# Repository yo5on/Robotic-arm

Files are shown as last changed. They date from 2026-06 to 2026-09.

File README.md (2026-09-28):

<div align="center">

projects

<samp><b>ESP32 ROBOTIC ARM</b></samp>

<samp>robotics · esp32 · c/c++ · embedded systems</samp>

</div>

---

<div align="center"><samp>An ESP32-based 4-DOF robotic arm controlled wirelessly using an RC transmitter and receiver. The project demonstrates embedded control, servo motor manipulation, wireless communication, and coordinated robotic movement for pick-and-place applications.</samp></div>

---

<div align="center">
<samp><b>Project Overview</b></samp>
</div>

<samp>This project implements a four-degree-of-freedom robotic arm using an ESP32 microcontroller and a FlySky RC transmitter and receiver.</samp>

<samp>The system converts wireless control inputs into servo motor movements, allowing independent control of the arm's base, shoulder, elbow, and gripper.</samp>

<samp>The project provides practical experience with:</samp>

- <samp>Embedded systems</samp>
- <samp>Wireless control</samp>
- <samp>Servo motor control</samp>
- <samp>Microcontroller programming</samp>
- <samp>Robotic motion</samp>
- <samp>Hardware interfacing</samp>
- <samp>Pick-and-place automation</samp>

---

<div align="center">
<samp><b>Project Images</b></samp>
</div>

<table align="center">
<tr><th><samp>Robotic Arm</samp></th><th><samp>Wiring Diagram</samp></th></tr>
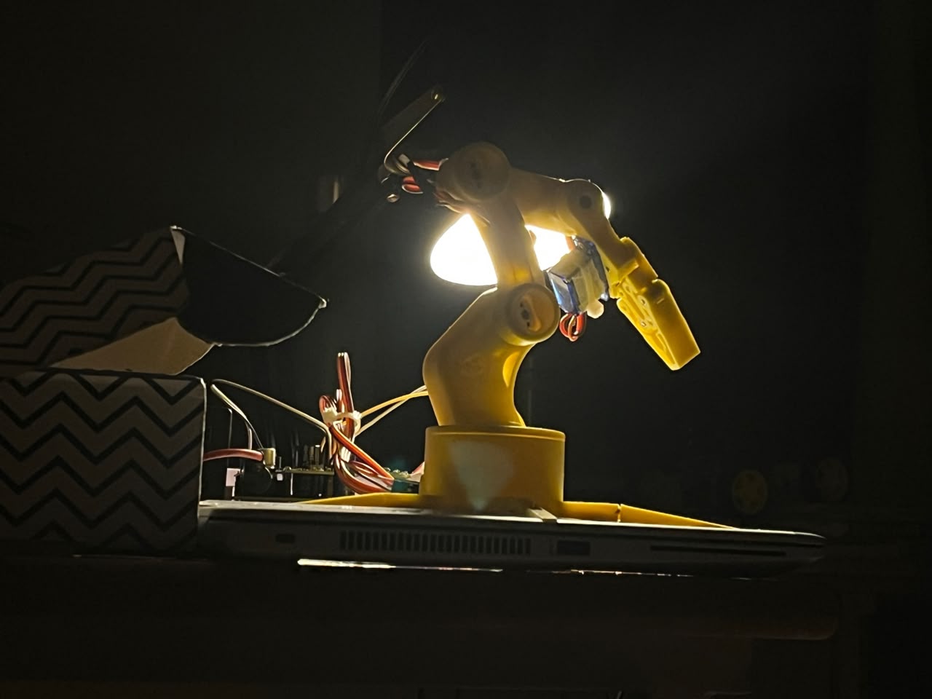
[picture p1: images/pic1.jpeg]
Robotic Arm
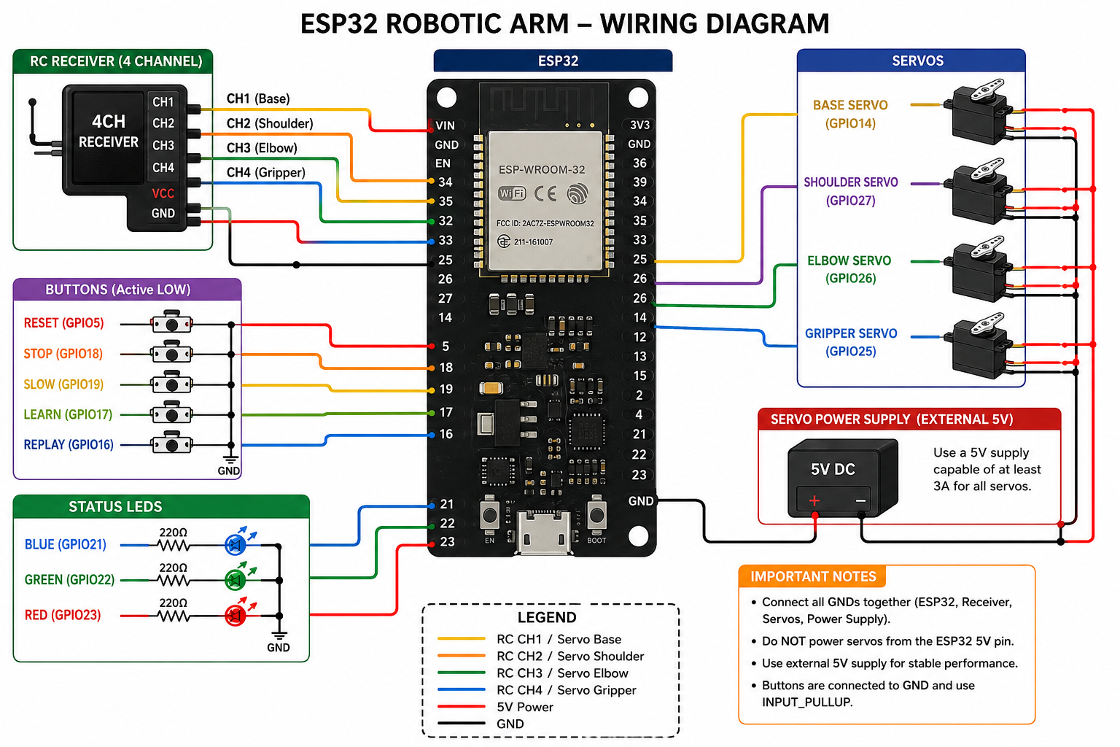
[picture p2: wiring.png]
Wiring Diagram
<tr><td></td><td></td></tr>
</table>

---

<div align="center">
<samp><b>Features</b></samp>
</div>

- <samp>Wireless RC control</samp>
- <samp>Four degrees of freedom</samp>
- <samp>Independent servo motor control</samp>
- <samp>Responsive robotic arm movement</samp>
- <samp>LED-based system status indication</samp>
- <samp>Push-button controls</samp>
- <samp>Pick-and-place functionality</samp>
- <samp>Modular hardware and software design</samp>
- <samp>Expandable architecture for future development</samp>

---

<div align="center">
<samp><b>Hardware Components</b></samp>
</div>

<table align="center">
<tr><th><samp>Component</samp></th><th><samp>Quantity</samp></th></tr>
<tr><td><samp>ESP32 Development Board</samp></td><td><samp>1</samp></td></tr>
<tr><td><samp>Servo Motors</samp></td><td><samp>4</samp></td></tr>
<tr><td><samp>FlySky Receiver</samp></td><td><samp>1</samp></td></tr>
<tr><td><samp>Push Buttons</samp></td><td><samp>5</samp></td></tr>
<tr><td><samp>LEDs</samp></td><td><samp>3</samp></td></tr>
<tr><td><samp>Robotic Arm Chassis</samp></td><td><samp>1</samp></td></tr>
<tr><td><samp>5V Power Supply</samp></td><td><samp>1</samp></td></tr>
<tr><td><samp>Connecting Wires</samp></td><td><samp>As required</samp></td></tr>
<tr><td><samp>Breadboard / PCB</samp></td><td><samp>Optional</samp></td></tr>
</table>

---

<div align="center">
<samp><b>Wiring</b></samp>
</div>

<samp>The complete wiring configuration is provided below.</samp>

<div align="center">Wiring Diagram</div>

---

<div align="center">
<samp><b>Repository Structure</b></samp>
</div>

```text
Robotic-arm/
│
├── 3dparts/
│   └── *.stl
├── images/
│   ├── pic1.jpeg
│   ├── pic2.jpeg
│   └── pic3.jpeg
├── README.md
├── code.ino
└── wiring.png
```

---

<div align="center">
<samp><b>Getting Started</b></samp>
</div>

<samp><b>Prerequisites</b></samp>

<samp>Before setting up the project, ensure that the following are available:</samp>

- <samp>Arduino IDE</samp>
- <samp>ESP32 board support package</samp>
- <samp>ESP32Servo library</samp>
- <samp>ESP32 development board</samp>
- <samp>FlySky transmitter and receiver</samp>
- <samp>Required servo motors</samp>
- <samp>Suitable 5V power supply</samp>

<samp><b>Clone the Repository</b></samp>

```bash
git clone https://github.com/yo5on/Robotic-arm.git
cd Robotic-arm
```

<samp><b>Open the Project</b></samp>

<samp>Open <code>code.ino</code> in the Arduino IDE.</samp>

<samp><b>Install Required Libraries</b></samp>

<samp>Install the following components through the Arduino IDE:</samp>

- <samp>ESP32 Board Package</samp>
- <samp>ESP32Servo Library</samp>

<samp><b>Configure the ESP32</b></samp>

<samp>1. Connect the ESP32 to the computer.</samp>

<samp>2. Select the appropriate ESP32 board from the Arduino IDE board menu.</samp>

<samp>3. Select the correct COM port.</samp>

<samp>4. Verify the wiring connections.</samp>

<samp>5. Open <code>code.ino</code>.</samp>

<samp><b>Upload the Code</b></samp>

<samp>Click <strong>Upload</strong> in the Arduino IDE and wait for the upload process to complete.</samp>

<samp>Once the code has been uploaded, power the robotic arm and transmitter/receiver system.</samp>

---

<div align="center">
<samp><b>Controls</b></samp>
</div>

<samp>The robotic arm is controlled through four RC channels:</samp>

<table align="center">
<tr><th><samp>Channel</samp></th><th><samp>Function</samp></th></tr>
<tr><td><samp>CH1</samp></td><td><samp>Base Rotation</samp></td></tr>
<tr><td><samp>CH2</samp></td><td><samp>Shoulder Movement</samp></td></tr>
<tr><td><samp>CH3</samp></td><td><samp>Elbow Movement</samp></td></tr>
<tr><td><samp>CH4</samp></td><td><samp>Gripper Control</samp></td></tr>
</table>

<samp>Servo limits and control ranges can be adjusted in the Arduino source code according to the mechanical configuration of the arm.</samp>

---

<div align="center">
<samp><b>System Architecture</b></samp>
</div>

```text
RC Transmitter
      |
      v
FlySky Receiver
      |
      v
     ESP32
      |
      +---- Base Servo
      |
      +---- Shoulder Servo
      |
      +---- Elbow Servo
      |
      +---- Gripper Servo
```

---

<div align="center">
<samp><b>Working Principle</b></samp>
</div>

<samp>1. The RC transmitter generates control signals based on user input.</samp>

<samp>2. The FlySky receiver receives the wireless signals.</samp>

<samp>3. The ESP32 reads the corresponding receiver channels.</samp>

<samp>4. The input values are mapped to appropriate servo positions.</samp>

<samp>5. The four servo motors move the robotic arm according to the received commands.</samp>

<samp>6. LEDs provide system status information.</samp>

<samp>7. Push buttons provide additional functionality such as mode selection, reset, or calibration.</samp>

---

<div align="center">
<samp><b>Applications</b></samp>
</div>

- <samp>Pick-and-place systems</samp>
- <samp>Embedded robotics</samp>
- <samp>Wireless robotic control</samp>
- <samp>Servo motor coordination</samp>
- <samp>Robotic manipulation</samp>
- <samp>Industrial automation concepts</samp>
- <samp>Autonomous robotic systems</samp>

---

<div align="center">
<samp><b>Future Improvements</b></samp>
</div>

- <samp>Inverse kinematics</samp>
- <samp>Preset position memory</samp>
- <samp>Mobile application control</samp>
- <samp>Wi-Fi and Bluetooth control</samp>
- <samp>Camera integration</samp>
- <samp>AI-based object detection</samp>
- <samp>Autonomous pick-and-place operations</samp>
- <samp>Motion planning and trajectory optimization</samp>
- <samp>Object tracking and classification</samp>

---

<div align="center">
<samp><b>Technologies</b></samp>
</div>

<table align="center">
<tr><th><samp>Category</samp></th><th><samp>Technology</samp></th></tr>
<tr><td><samp>Microcontroller</samp></td><td><samp>ESP32</samp></td></tr>
<tr><td><samp>Programming</samp></td><td><samp>C/C++</samp></td></tr>
<tr><td><samp>Development Environment</samp></td><td><samp>Arduino IDE</samp></td></tr>
<tr><td><samp>Wireless Control</samp></td><td><samp>FlySky RC Transmitter/Receiver</samp></td></tr>
<tr><td><samp>Actuators</samp></td><td><samp>Servo Motors</samp></td></tr>
<tr><td><samp>Communication</samp></td><td><samp>RC Receiver Channels</samp></td></tr>
</table>

---

<div align="center">
<samp><b>Author</b></samp>
</div>

<div align="center">
<samp><strong>Yoson</strong></samp>

<samp>Computer Science student interested in AI/ML, robotics, embedded systems, and automation.</samp>

<samp>GitHub: https://github.com/yo5on</samp>
</div>

---

<div align="center">
<samp><b>License</b></samp>
</div>

<samp>This project is intended for educational and personal use. You are free to explore, modify, and extend the project for your own robotics and embedded systems experiments.</samp>

<div align="center">
<samp>If you find this project useful, consider giving the repository a star.</samp>
</div>

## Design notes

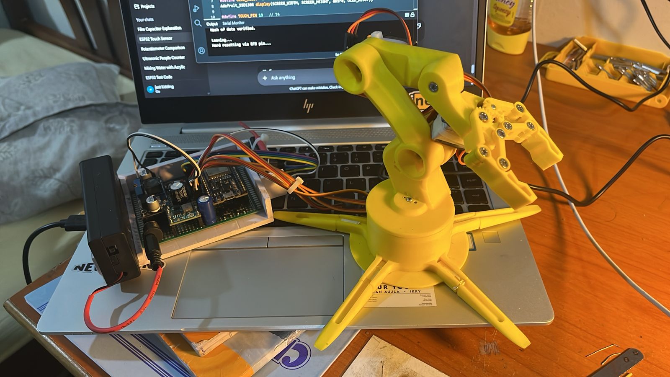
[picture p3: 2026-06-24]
images/pic2.jpeg

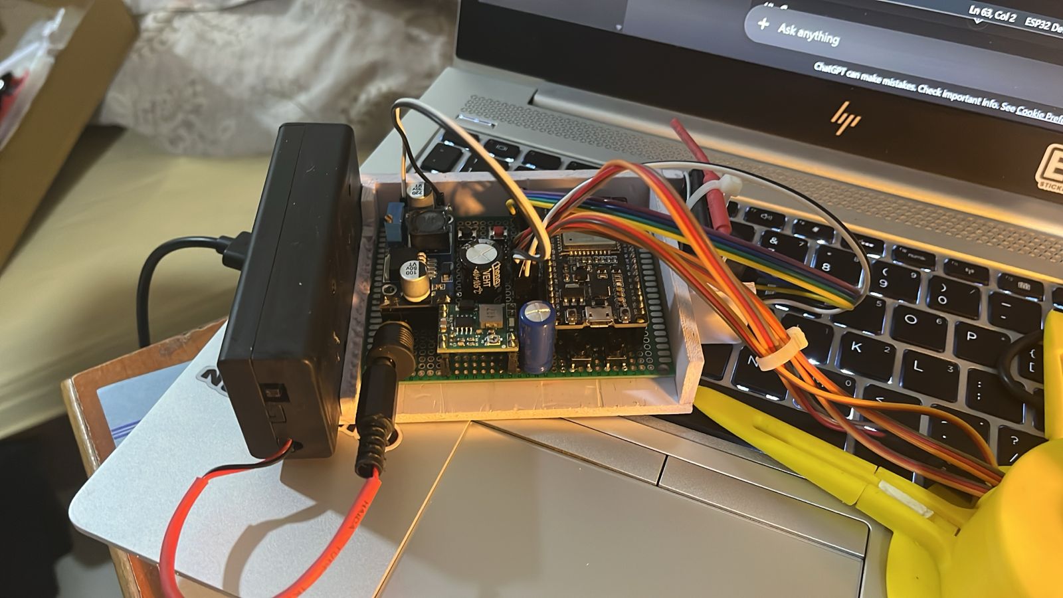
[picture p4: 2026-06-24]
images/pic3.jpeg

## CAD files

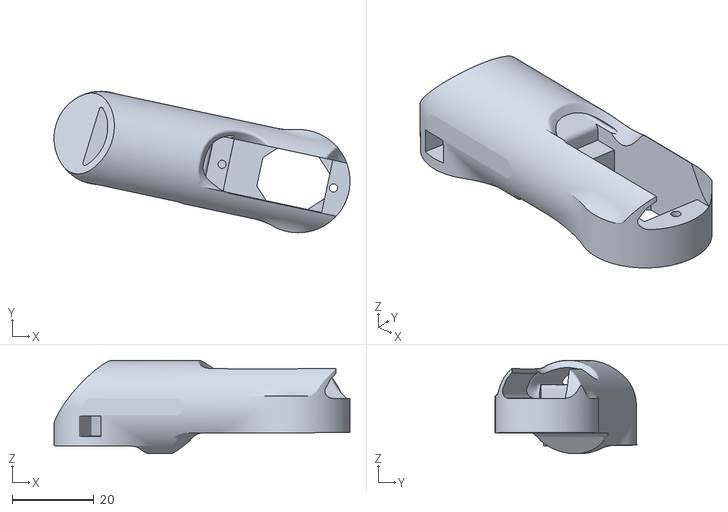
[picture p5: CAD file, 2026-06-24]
3dparts/arm.stl
72.2 x 34.5 x 22.8

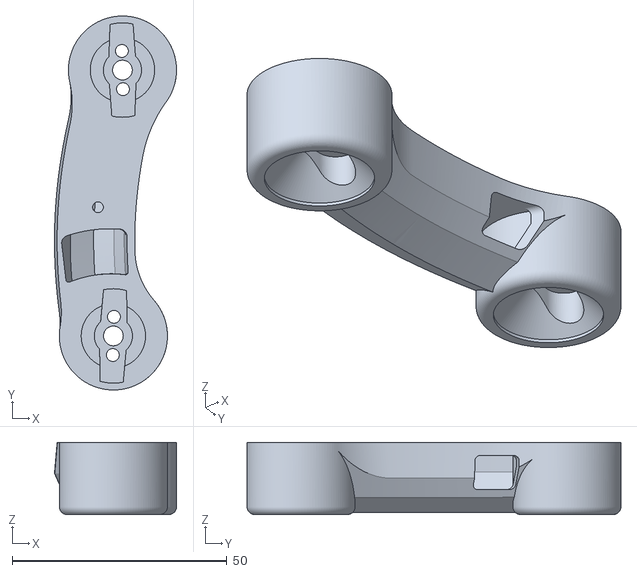
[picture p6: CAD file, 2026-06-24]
3dparts/forearm.stl
28.5 x 87.2 x 16.8

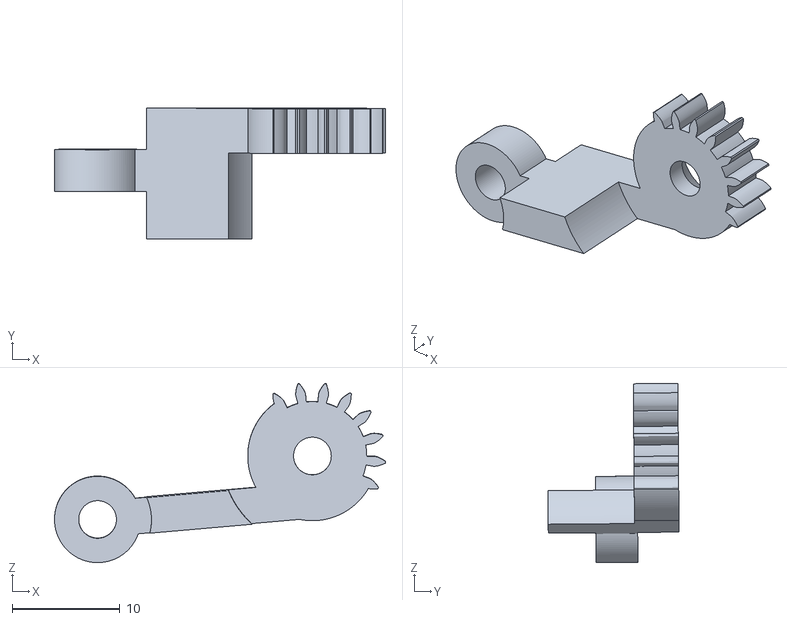
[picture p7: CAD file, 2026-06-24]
3dparts/gear2.stl
30.7 x 12.2 x 16.6

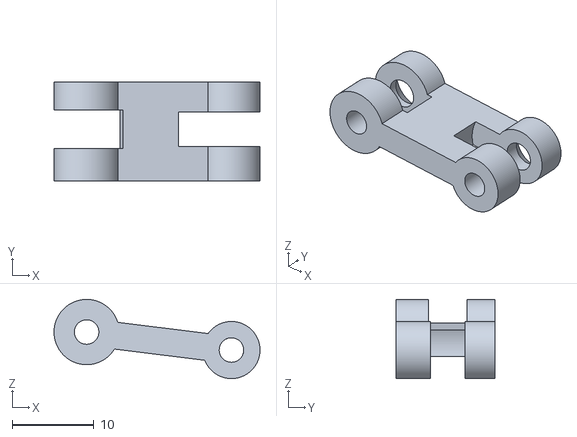
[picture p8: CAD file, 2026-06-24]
3dparts/bar1.stl
25.3 x 12.1 x 9.70

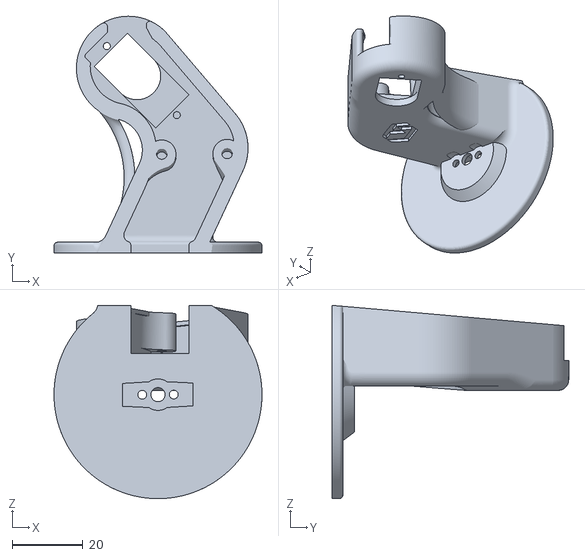
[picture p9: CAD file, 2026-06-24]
3dparts/centralshaft.stl
58.8 x 66.9 x 54.6

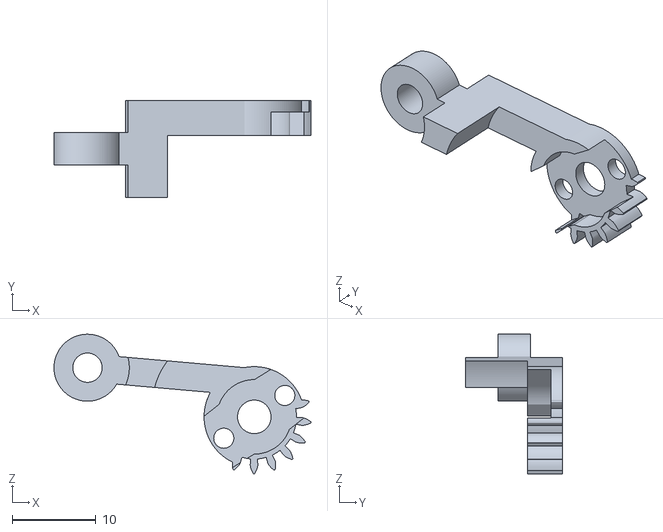
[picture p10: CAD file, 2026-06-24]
3dparts/gear1.stl
30.7 x 11.5 x 16.7

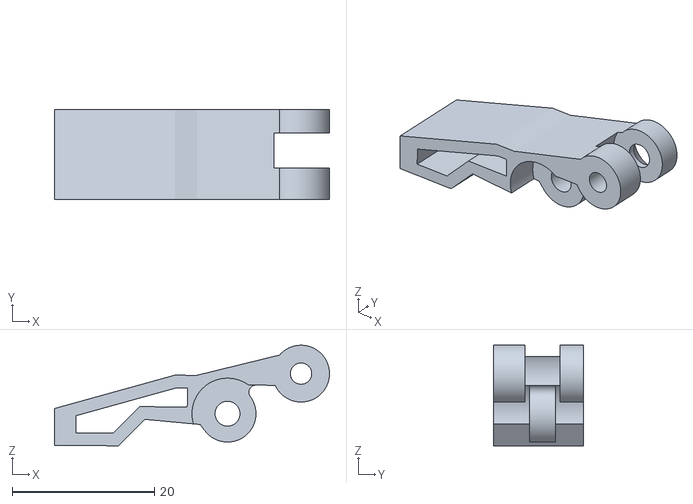
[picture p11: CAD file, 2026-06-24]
3dparts/claw1.stl
38.7 x 12.6 x 14.2

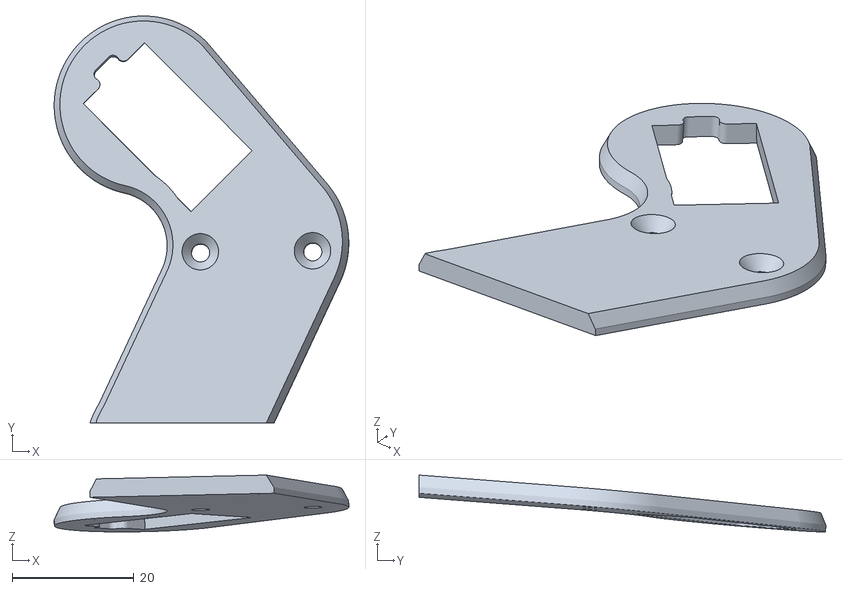
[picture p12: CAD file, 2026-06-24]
3dparts/shaftcover.stl
48.5 x 67.0 x 9.36

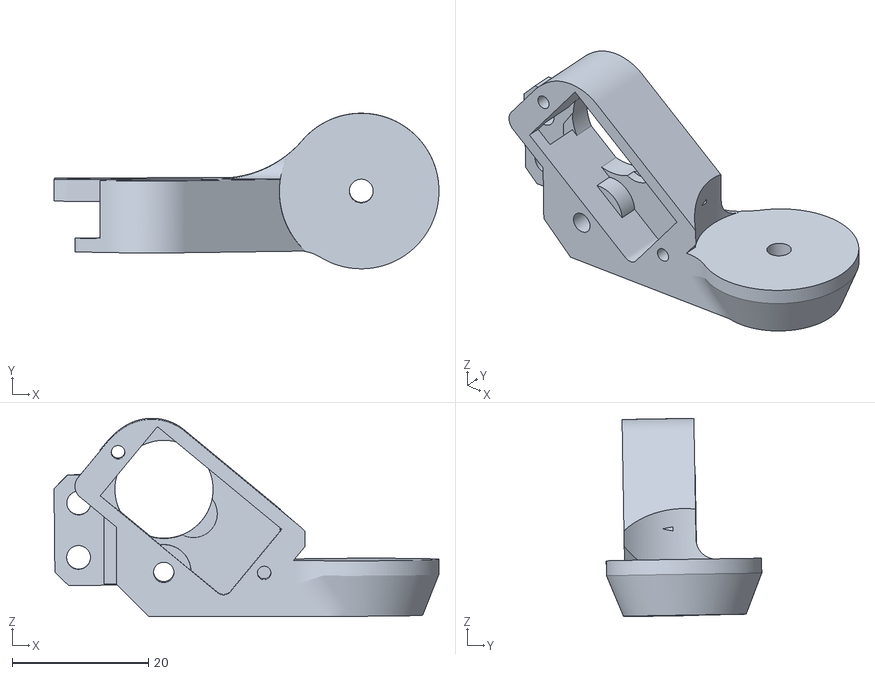
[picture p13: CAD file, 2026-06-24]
3dparts/clawbase.stl
56.5 x 22.8 x 29.1

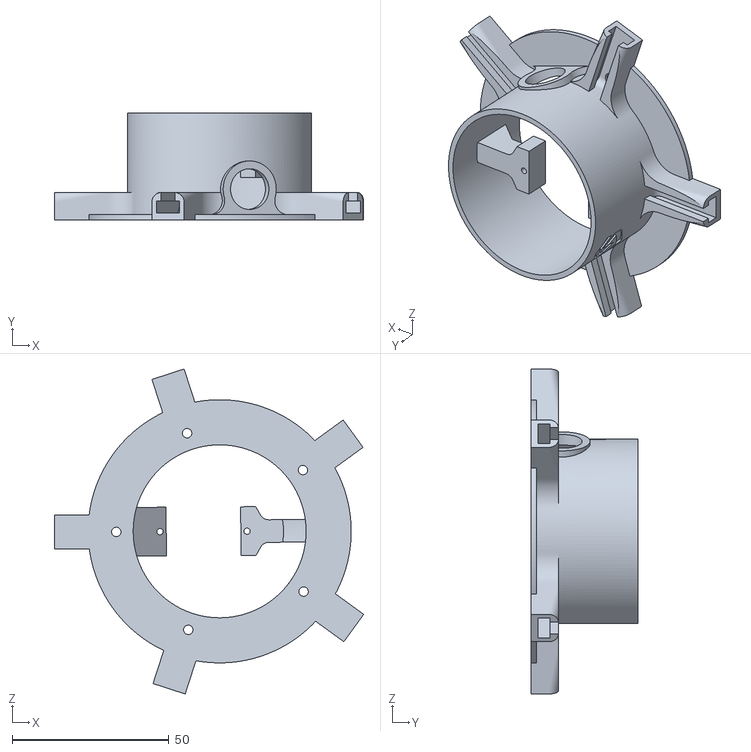
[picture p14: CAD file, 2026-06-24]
3dparts/base.stl
98.8 x 34.1 x 103.8

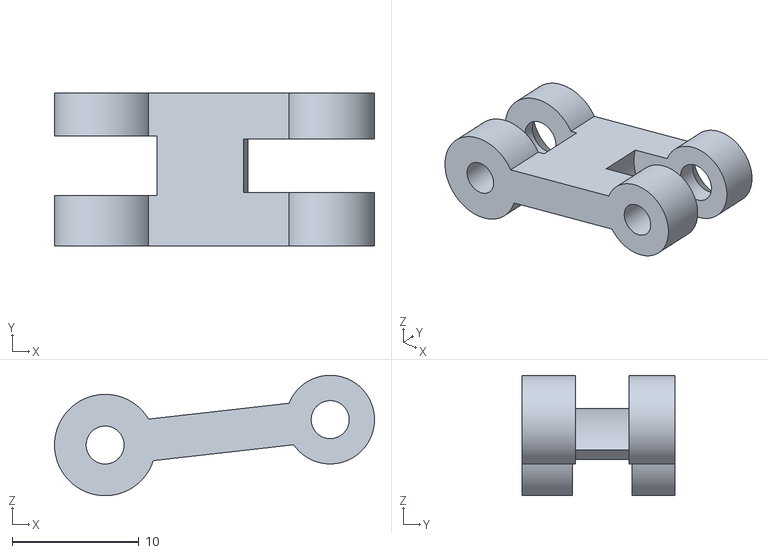
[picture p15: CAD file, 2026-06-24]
3dparts/bar2.stl
25.3 x 12.1 x 9.50

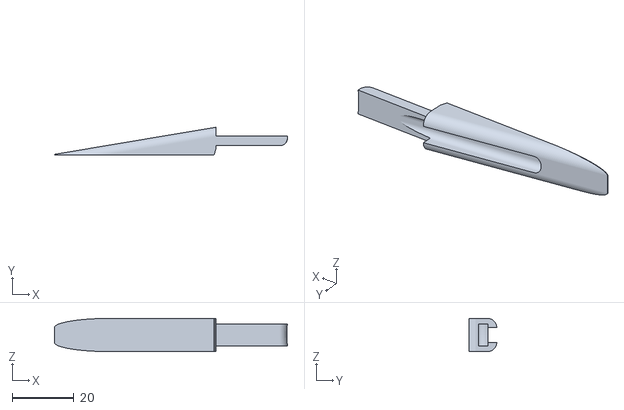
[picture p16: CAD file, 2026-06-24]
3dparts/leg.stl
75.7 x 8.96 x 10.8

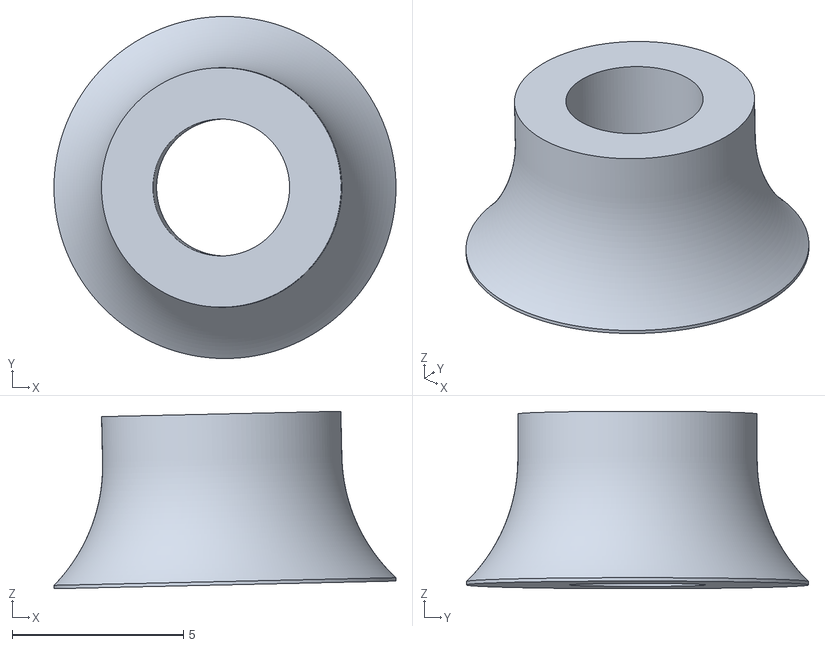
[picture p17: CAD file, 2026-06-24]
3dparts/smalltube.stl
10.00 x 10.00 x 5.19

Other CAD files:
3dparts/claw2.stl

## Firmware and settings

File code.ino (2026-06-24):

#include <Arduino.h>
#include <ESP32Servo.h>

// ===== Servos =====
Servo baseServo, shoulderServo, elbowServo, gripperServo;

// ===== Receiver pins =====
const int ch1Pin = 34;
const int ch2Pin = 35;
const int ch3Pin = 32;
const int ch4Pin = 33;

// ===== Servo pins =====
const int basePin = 14;
const int shoulderPin = 27;
const int elbowPin = 26;
const int gripperPin = 25;

// ===== Button pins =====
#define BTN_RESET   5
#define BTN_STOP    18
#define BTN_SLOW    19
#define BTN_LEARN   17
#define BTN_REPLAY  16

// ===== LED pins =====
#define LED_BLUE   21
#define LED_GREEN  22
#define LED_RED    23

// ===== Timing =====
const unsigned long SHORT_PRESS = 800;
const unsigned long DOUBLE_CLICK_GAP = 400;

// ===== Speed =====
bool slowMode = false;
unsigned long moveDelay = 2;
const unsigned long SLOW_DELAY = 25;

// ===== Button struct =====
struct Button {
  int pin;
  bool pressed;
  unsigned long t;
};

Button btnReset  = {BTN_RESET, false, 0};
Button btnStop   = {BTN_STOP, false, 0};
Button btnSlow   = {BTN_SLOW, false, 0};
Button btnLearn  = {BTN_LEARN, false, 0};
Button btnReplay = {BTN_REPLAY, false, 0};

// ===== States =====
bool stopMode = false;
bool learnMode = false;
bool replayOnce = false;
bool replayLoop = false;

// ===== Replay double click =====
bool replayPending = false;
unsigned long replayClickTime = 0;

// ===== Memory =====
#define MAX_STEPS 200
int baseMem[MAX_STEPS], shoulderMem[MAX_STEPS], elbowMem[MAX_STEPS], gripperMem[MAX_STEPS];
int stepCount = 0;

// ===== Reset confirmation =====
bool resetConfirm = false;
unsigned long resetTimer = 0;
int resetStep = 0;
bool resetState = false;

// ===== Blink timers =====
unsigned long redTimer = 0, blueTimer = 0;
int redStep = 0, blueStep = 0;
bool redState = false, blueState = false;

// ===== Button handler =====
void handleButton(Button &b, void (*action)()) {
  if (digitalRead(b.pin) == LOW && !b.pressed) {
    b.pressed = true;
    b.t = millis();
  }
  if (digitalRead(b.pin) == HIGH && b.pressed) {
    b.pressed = false;
    if (millis() - b.t < SHORT_PRESS) action();
  }
}

// ===== Button actions =====
void resetShort() {
  stopMode = false;
  baseServo.write(90);
  shoulderServo.write(90);
  elbowServo.write(90);
  gripperServo.write(45);

  resetConfirm = true;
  resetStep = 0;
  resetTimer = millis();
}

void stopShort() { stopMode = !stopMode; }

void slowShort() {
  slowMode = !slowMode;
  moveDelay = slowMode ? SLOW_DELAY : 2;
}

void learnShort() {
  learnMode = !learnMode;
  if (learnMode) stepCount = 0;
}

void replayShort() {
  unsigned long now = millis();
  if (replayPending && (now - replayClickTime <= DOUBLE_CLICK_GAP)) {
    replayLoop = !replayLoop;
    replayOnce = false;
    replayPending = false;
  } else {
    replayPending = true;
    replayClickTime = now;
  }
}

// ===== Blink helpers =====
bool doubleBlink(unsigned long &t, int &s, bool &st) {
  const unsigned long p[4] = {120,120,120,600};
  if (millis() - t >= p[s]) {
    t = millis();
    s = (s + 1) % 4;
    st = (s == 0 || s == 2);
  }
  return st;
}

bool resetBlink() {
  const unsigned long p[4] = {120,120,120,600};
  if (millis() - resetTimer >= p[resetStep]) {
    resetTimer = millis();
    resetStep++;
    resetState = (resetStep == 1 || resetStep == 3);
    if (resetStep >= 4) {
      resetConfirm = false;
      resetState = false;
    }
  }
  return resetState;
}

void setup() {
  pinMode(ch1Pin, INPUT);
  pinMode(ch2Pin, INPUT);
  pinMode(ch3Pin, INPUT);
  pinMode(ch4Pin, INPUT);

  pinMode(BTN_RESET, INPUT_PULLUP);
  pinMode(BTN_STOP, INPUT_PULLUP);
  pinMode(BTN_SLOW, INPUT_PULLUP);
  pinMode(BTN_LEARN, INPUT_PULLUP);
  pinMode(BTN_REPLAY, INPUT_PULLUP);

  pinMode(LED_RED, OUTPUT);
  pinMode(LED_GREEN, OUTPUT);
  pinMode(LED_BLUE, OUTPUT);

  baseServo.attach(basePin);
  shoulderServo.attach(shoulderPin);
  elbowServo.attach(elbowPin);
  gripperServo.attach(gripperPin);

  baseServo.write(90);
  shoulderServo.write(90);
  elbowServo.write(90);
  gripperServo.write(45);
}

void loop() {

  handleButton(btnReset, resetShort);
  handleButton(btnStop, stopShort);
  handleButton(btnSlow, slowShort);
  handleButton(btnLearn, learnShort);
  handleButton(btnReplay, replayShort);

  if (replayPending && millis() - replayClickTime > DOUBLE_CLICK_GAP) {
    if (!replayLoop) replayOnce = true;
    replayPending = false;
  }

  // ===== RESET CONFIRM =====
  if (resetConfirm) {
    bool s = resetBlink();
    digitalWrite(LED_RED, s);
    digitalWrite(LED_GREEN, s);
    digitalWrite(LED_BLUE, s);
    return;
  }

  // ===== CLEAR LEDs =====
  digitalWrite(LED_RED, LOW);
  digitalWrite(LED_GREEN, LOW);
  digitalWrite(LED_BLUE, LOW);

  // ===== STOP (highest priority) =====
  if (stopMode) {
    digitalWrite(LED_RED, HIGH);
    return;
  }

  // ===== STATE LEDs (can coexist) =====
  if (learnMode) {
    digitalWrite(LED_GREEN, HIGH);
  }

  if (replayLoop) {
    digitalWrite(LED_BLUE, doubleBlink(blueTimer, blueStep, blueState));
  }
  else if (replayOnce) {
    digitalWrite(LED_BLUE, HIGH);
  }

  // ===== SPEED MODIFIER (overlay) =====
  if (slowMode) {
    digitalWrite(LED_RED, doubleBlink(redTimer, redStep, redState));
  }

  // ===== Replay once =====
  if (replayOnce && stepCount > 0) {
    for (int i = 0; i < stepCount; i++) {
      baseServo.write(baseMem[i]);
      shoulderServo.write(shoulderMem[i]);
      elbowServo.write(elbowMem[i]);
      gripperServo.write(gripperMem[i]);
      delay(moveDelay);
    }
    replayOnce = false;
  }

  // ===== Replay loop (non-blocking) =====
  if (replayLoop && stepCount > 0) {
    static int i = 0;
    static unsigned long lastMove = 0;
    if (millis() - lastMove >= moveDelay) {
      lastMove = millis();
      baseServo.write(baseMem[i]);
      shoulderServo.write(shoulderMem[i]);
      elbowServo.write(elbowMem[i]);
      gripperServo.write(gripperMem[i]);
      i = (i + 1) % stepCount;
    }
  }

  // ===== Live RC control =====
  int pwm1 = pulseIn(ch1Pin, HIGH, 25000);
  int pwm2 = pulseIn(ch2Pin, HIGH, 25000);
  int pwm3 = pulseIn(ch3Pin, HIGH, 25000);
  int pwm4 = pulseIn(ch4Pin, HIGH, 25000);

  if (pwm1 >= 1100 && pwm1 <= 1800)
    baseServo.write(map(pwm1, 1100, 1800, 0, 180));
  if (pwm2 >= 1200 && pwm2 <= 1800)
    shoulderServo.write(map(pwm2, 1200, 1800, 20, 160));
  if (pwm3 >= 1200 && pwm3 <= 1900)
    elbowServo.write(map(pwm3, 1200, 1900, 30, 150));
  if (pwm4 >= 1000 && pwm4 <= 2000)
    gripperServo.write(map(pwm4, 1000, 2000, 0, 90));

  // ===== Record =====
  if (learnMode && stepCount < MAX_STEPS) {
    baseMem[stepCount] = baseServo.read();
    shoulderMem[stepCount] = shoulderServo.read();
    elbowMem[stepCount] = elbowServo.read();
    gripperMem[stepCount] = gripperServo.read();
    stepCount++;
    delay(moveDelay);
  }
}

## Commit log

2026-09-28 style: unify Robotic Arm README typography and layout
2026-10-29 docs: add verified robotic arm GPIO mapping and power notes
